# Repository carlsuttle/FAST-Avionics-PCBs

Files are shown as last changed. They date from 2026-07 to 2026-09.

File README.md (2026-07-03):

# FAST Avionics PCBs

KiCad 10 hardware designs for FAST avionics.

## Projects

- `FLIGHT CONTROLLER/` — FAST flight-controller schematic, PCB, fabrication outputs, component libraries, and design notes.
- `AS_GPS_XIAO_OUTBOARD/` — GPS/XIAO outboard schematic, PCB, fabrication outputs, and supporting libraries.

Open each `.kicad_pro` file with KiCad 10 or newer.

Local KiCad preferences, lock files, autosaves, backups, and history snapshots are intentionally excluded from version control.

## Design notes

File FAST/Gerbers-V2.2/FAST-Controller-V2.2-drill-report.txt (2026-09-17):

Drill report for FAST Controller.kicad_pcb
Created on 2026-09-17T15:46:22

Copper Layer Stackup:
    =============================================================
    L1 :  F.Cu                      front
    L2 :  B.Cu                      back

Drill file 'FAST Controller-PTH.drl' contains
    plated through holes:
    =============================================================
    T1  0.300mm  0.0118"  (19 holes))
    T2  0.400mm  0.0157"  (6 holes))
    T3  0.600mm  0.0236"  (2 holes))
    T4  0.700mm  0.0276"  (4 holes))
    T5  0.800mm  0.0315"  (36 holes))
    T6  0.889mm  0.0350"  (14 holes))
    T7  0.950mm  0.0374"  (36 holes))
    T8  1.000mm  0.0394"  (52 holes))

    Total plated holes count 169

Drill file 'FAST Controller-NPTH.drl' contains
    unplated through holes:
    =============================================================
    T1  3.200mm  0.1260"  (4 holes))

    Total unplated holes count 4

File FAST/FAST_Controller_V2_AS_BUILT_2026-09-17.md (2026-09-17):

# FAST Controller V2 as-built record — 2026-09-17

The manufactured FAST Controller V2 board has been installed and bench-tested
in the aircraft. The corrected production files are V2.2; they supersede the
V2.1 Gerbers.

## As-built corrections

- PMEG4050EP isolation diodes are installed in the corrected direction so the
  ESC BEC or power-module BEC can power `5V_LOGIC`, without `5V_LOGIC`
  back-feeding either BEC input.
- A field link connects the watchdog output/test point to CD74HCT157E select.
- A 10 kOhm pull-down from mux select to ground is fitted so loss of watchdog
  drive selects receiver PWM.
- The CRSF 5 V pin is intentionally unconnected. The receiver and servo rail
  are powered through the PWM harness: pin 5 ground and pin 6 ESC-BEC 5 V on
  each six-pin JST-XH receiver connector.
- The CRSF ground pad on its connector is not relied upon for receiver return;
  receiver ground is present through the PWM harness. A wire link to nearby
  ground test point TP3 remains the available repair if a dedicated CRSF
  ground is required.

## Confirmed connector/pin mapping

- J8 through J15 use the standard servo order: pin 1 ground, pin 2
  `+5V_ESC_BEC`, and pin 3 signal.
- J8 is servo output channel 1 and J15 is servo output channel 8.
- Board channel 8 (`TEENSY_PWM8_RAW`) is routed to Teensy D1, not Teensy D8.
- Teensy D8 is board channel 7 (`TEENSY_PWM7_RAW`).
- Flaps are therefore implemented in firmware as CRSF channel 8 -> Teensy D1
  -> board channel 8 -> J15.

## Integration result

All installed servo channels were confirmed operational from Teensy control,
and receiver PWM failover was confirmed through the hardware multiplexers.
IMU, ESP_AIR, ESP_OUTBOARD, CRSF, SD recording, file listing, and flight-log
replay were also verified after installation.

## V2.2 production correction

The PCB net assignments for J8 through J15 were corrected from the V2.1
pin-1-power/pin-2-ground order to pin 1 ground, pin 2 `+5V_ESC_BEC`, and pin 3
signal. Use `FAST-Controller-V2.2-Gerbers-2026-09-17.zip` for any new boards.

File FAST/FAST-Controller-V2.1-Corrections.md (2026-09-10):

# FAST Controller V2.1 — Production Corrections

Date: 2026-09-10

This note records faults discovered after manufacture of the original V2 board and the corrections incorporated into the V2.1 design files and manufacturing package.

## 1. CRSF receiver ground at J4

### Error

J4 pin 2 was assigned to GND in the schematic, but its copper-pour connection formed an isolated island. KiCad therefore showed the pad surrounded by GND-coloured copper even though it had no conductive path to the main board ground. The original DRC report's zone-to-zone unconnected warnings were incorrectly treated as harmless.

### V2.1 correction

The assembly requires an insulated wire link from **J4 pin 2 to TP3**. Both points are through-hole and TP3 is a confirmed main-ground point. The instruction is also printed on the bottom silkscreen:

`FIT INSULATED LINK: J4-2 TO TP3`

On already-manufactured V2 boards, fit the same link. J7/J8 grounds may provide another receiver-ground path in normal installation, but they are not a substitute for making the CRSF connector ground independently correct.

### Verification

Continuity test before power-up: J4 pin 2 to TP3 and to the Teensy GND pins must measure approximately zero ohms.

## 2. Logic-supply isolation diodes D1 and D2

### Error

D1 and D2 were electrically reversed. Their old orientation allowed the +5V_LOGIC rail to feed back toward the BEC source rails, opposite to the intended isolation behaviour.

### V2.1 correction

Both diode symbols and both PCB footprints have been reversed while retaining PMEG4050EP Schottky diodes:

- D1: anode to +5V_PM_BEC; cathode to +5V_LOGIC.
- D2: anode to +5V_ESC_BEC; cathode to +5V_LOGIC.

Either BEC can now supply +5V_LOGIC, while +5V_LOGIC cannot back-power either BEC rail. Observe the V2.1 footprint polarity marking when fitting the parts.

### Verification

With the board unpowered, diode-test mode should conduct from each BEC source rail toward +5V_LOGIC and block in the reverse direction.

## 3. Watchdog multiplexer-select default state

### Error

The ADM706 watchdog output drives MUX_SELECT, but the line had no discrete pull-down. Its fail-safe state could therefore be uncertain while the watchdog output or its supply was inactive.

### V2.1 correction

R30, 10 kΩ, 0805 hand-solder footprint, has been added from MUX_SELECT to GND. The resistor is connected directly to the existing MUX_SELECT trace and forces the receiver-PWM path to its safe default state when the watchdog is not actively driving the line.

### Verification

With the board unpowered, measure approximately 10 kΩ from MUX_SELECT to GND. During a watchdog timeout, confirm that MUX_SELECT is low and the CD74HCT157 multiplexers select the receiver PWM inputs.

## Manufacturing-package status

The corrected manufacturing output is identified as **FAST Controller V2.1**. Do not send the earlier V2 Gerber ZIP for a new production run. The V2.1 package includes the updated diode orientation, R30 pads and markings, board version marking, and the mandatory J4-to-TP3 insulated-link assembly instruction.

KiCad's final geometry check reports zero clearance, short-circuit, footprint, and silkscreen violations. It intentionally retains two unconnected-zone findings for the J4 ground island because the connection is completed by the specified insulated assembly link rather than PCB copper.

## Required pre-flight checks

1. Confirm the J4 pin 2 to TP3 link is installed and insulated.
2. Confirm D1 and D2 polarity by diode test.
3. Confirm +5V_ESC_BEC and +5V_PM_BEC are isolated from one another.
4. Confirm R30 measures 10 kΩ from MUX_SELECT to GND.
5. Power the board from each BEC source separately and verify +5V_LOGIC.
6. Test watchdog timeout and all eight receiver/Teensy servo-output paths before flight.

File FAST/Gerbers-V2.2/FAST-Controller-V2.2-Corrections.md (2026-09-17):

# FAST Controller V2.2 production correction

Date: 2026-09-17

V2.2 supersedes the V2.1 Gerbers. Servo output connectors J8 through J15 now
use the confirmed standard order:

- pin 1: GND
- pin 2: +5V_ESC_BEC
- pin 3: PWM signal

The +5V_ESC_BEC copper spine was rerouted from pin 1 to pin 2, and both copper
zones were refilled. KiCad DRC reports zero violations. Its two remaining
unconnected-item messages are the pre-existing duplicate ground-zone artifacts
at the zone origin (20.5 mm, 20.5 mm), not physical pads or routed nets.

Production archive: `FAST-Controller-V2.2-Gerbers-2026-09-17.zip`.

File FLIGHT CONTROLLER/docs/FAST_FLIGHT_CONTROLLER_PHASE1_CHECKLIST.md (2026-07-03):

# FAST Flight Controller Rev A, Phase 1 Checklist

- [x] Teensy library found
- [x] XIAO library found
- [x] Teensy symbol placed
- [x] XIAO symbol placed
- [x] Teensy footprint assigned
- [x] XIAO footprint assigned
- [x] FAST_SPI_SCK wired
- [x] FAST_SPI_MOSI_ESP_TO_TEENSY_SDI wired
- [x] FAST_SPI_MISO_TEENSY_SDO_TO_ESP wired
- [x] FAST_SPI_CS wired
- [x] FAST_DATA_READY wired
- [x] MOSI/MISO direction warning checked
- [x] No SD card wiring added in Phase 1
- [x] No PCB routing added in Phase 1
- [x] Schematic opens in KiCad
- [x] ERC status noted

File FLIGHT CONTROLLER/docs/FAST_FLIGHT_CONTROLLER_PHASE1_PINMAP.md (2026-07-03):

# FAST Flight Controller Rev A, Phase 1 Pinmap

## Core Teensy <-> ESP_AIR Transport Mapping

```text
Teensy pin 13 -> ESP GPIO7  / D8   SCK
Teensy pin 12 -> ESP GPIO8  / D9   ESP MOSI -> Teensy slave SDI
Teensy pin 11 -> ESP GPIO9  / D10  ESP MISO <- Teensy slave SDO
Teensy pin 10 -> ESP GPIO44 / D7   CS
Teensy pin 9  -> ESP GPIO43 / D6   DATA_READY
```

## MOSI/MISO Direction Warning

ESP32-S3 is the SPI master.
Teensy 4.0 is the SPI slave.
Do not map MOSI/MISO by matching Teensy silkscreen labels.
Map by signal direction:
ESP MOSI drives Teensy slave SDI.
ESP MISO receives Teensy slave SDO.

## Phase 1 Net Labels

```text
FAST_SPI_SCK
FAST_SPI_MOSI_ESP_TO_TEENSY_SDI
FAST_SPI_MISO_TEENSY_SDO_TO_ESP
FAST_SPI_CS
FAST_DATA_READY
```

## Phase 1 Scope Notes

SD card pins are not wired in Phase 1.
Power input, regulation, and protection circuits are not designed in Phase 1.
PCB placement and routing are not part of Phase 1.

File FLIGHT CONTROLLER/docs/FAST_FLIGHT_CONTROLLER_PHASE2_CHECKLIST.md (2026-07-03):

# FAST Flight Controller Rev A - Phase 2 Checklist

- [x] ESC/BEC input connector added
- [x] `+5V_ESC_BEC` net created
- [x] Teensy VIN connected to `+5V_ESC_BEC`
- [x] XIAO VBUS/5V connected to `+5V_ESC_BEC`
- [x] All current module GND pins connected
- [x] Input capacitors added
- [x] Test points added
- [x] `TEENSY_3V3` and `ESP_3V3` not shorted together
- [x] Phase 1 transport nets preserved
- [x] SD pins reserved, not no-connected
- [x] No SD card wiring added in Phase 2
- [x] No PCB routing added in Phase 2
- [x] ERC run
- [x] ERC report saved

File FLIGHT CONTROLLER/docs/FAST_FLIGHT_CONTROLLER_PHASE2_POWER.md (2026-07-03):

# FAST Flight Controller Rev A - Phase 2 Power

## Power Source

The board is powered from an external ESC/BEC that provides regulated `+5V_ESC_BEC` and `GND`.

No onboard regulator was added in Phase 2.
No PCB placement or routing was added in Phase 2.

## 5 V Distribution

`+5V_ESC_BEC` powers:

- J1 pin 1, `ESC_BEC_5V_IN`
- U1 Teensy 4.0 carrier `VIN`
- U2 XIAO ESP32-S3 `VBUS` / 5 V input
- C1, C2, C3 input capacitors
- TP1 test point

J1 pin 2 is connected to `GND`.

## Ground

`GND` connects:

- J1 pin 2
- U1 Teensy `GND1` and `GND2`
- U2 XIAO `GND`
- C1, C2, C3 return pins
- TP2 test point

## 3.3 V Rails

The Teensy and XIAO 3.3 V pins are treated as module-generated rails.

- U1 Teensy `3V3` is labeled `TEENSY_3V3` and connects only to TP3.
- U2 XIAO `3V3` is labeled `ESP_3V3` and connects only to TP4.

`TEENSY_3V3` and `ESP_3V3` are not connected together in Phase 2.
Neither 3.3 V rail is used as the main board power input.

## Input Capacitors

- C1: `100 uF >=10V bulk`, provisional footprint `fast_teensy:C_Radial_D5.0mm_P2.00mm`
- C2: `10 uF >=10V`, provisional footprint `fast_teensy:C_0805`
- C3: `100 nF`, provisional footprint `fast_teensy:C_0805`

All three capacitors connect from `+5V_ESC_BEC` to `GND`.

## Test Points

- TP1: `+5V_ESC_BEC`
- TP2: `GND`
- TP3: `TEENSY_3V3`
- TP4: `ESP_3V3`

## Reserved Pins

No SD card wiring was added in Phase 2.
ESP GPIO1 / D0, GPIO2 / D1, GPIO5 / D4, and GPIO6 / D5 remain reserved for Phase 3 SD card wiring and were not no-connected.

## Remaining ERC Status

ERC was run and saved to `docs/FAST_FLIGHT_CONTROLLER_PHASE2_ERC.rpt`.

Remaining electrical errors are unconnected pins left open for later phases or future design decisions. They were not hidden with no-connect markers.

The ERC report also contains footprint-link warnings for the local `fast_teensy` footprint nickname even though the project-local `fp-lib-table` contains the `fast_teensy` entry and the footprints exist under `${KIPRJMOD}/lib/footprints/fast_teensy.pretty`. These warnings are documented and not suppressed.

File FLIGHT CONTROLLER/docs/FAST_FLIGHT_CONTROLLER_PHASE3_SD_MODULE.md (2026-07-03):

# FAST Flight Controller Phase 3 SD Module

## Design

J2 is a plug-in SD-card breakout module, not a raw microSD socket. The module is intended to be soldered into the FAST Flight Controller PCB so that its daughterboard stands vertically, perpendicular to the main PCB.

J2 uses the project-local symbol `fast_common:SD_Module_1x06` and the provisional footprint `fast_common:SD_Module_1x06_Vertical_Daughterboard`.

## Header Pin Order

The module label order, from top to bottom, is:

| Pin | Label |
| --- | --- |
| 1 | CS |
| 2 | SCK |
| 3 | MOSI |
| 4 | MISO |
| 5 | VCC |
| 6 | GND |

## Electrical Connections

| J2 pin | Net | ESP_AIR connection |
| --- | --- | --- |
| 1 CS | `ESP_SD_CS` | U2 GPIO2 / D1 |
| 2 SCK | `ESP_SD_SCK` | U2 GPIO5 / D4 |
| 3 MOSI | `ESP_SD_MOSI` | U2 GPIO6 / D5 |
| 4 MISO | `ESP_SD_MISO` | U2 GPIO1 / D0 |
| 5 VCC | `+5V_ESC_BEC` | External regulated 5 V BEC rail |
| 6 GND | `GND` | Common ground |

VCC currently connects to `+5V_ESC_BEC` because the selected style of SD breakout module appears to include onboard 3.3 V regulation and interface circuitry. Do not change J2 VCC to `ESP_3V3` unless the exact physical module is later confirmed to require a 3.3 V input.

## Mechanical Notes

The physical module, header side, pin-1 position, board-facing side, and clearance envelope must be visually checked against the provisional footprint before PCB layout.

Mechanical support or retention may be needed because the SD module stands vertically and can apply leverage to the six-pin soldered header during card insertion, removal, vibration, or impact.

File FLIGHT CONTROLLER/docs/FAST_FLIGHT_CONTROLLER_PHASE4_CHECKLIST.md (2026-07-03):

# FAST Flight Controller Phase 4 Checklist

- [x] J3 IMU connector added
- [x] J4 CRSF connector added
- [x] J5 AS_GPS_XIAO_OUTBOARD connector added
- [x] J3 power pin correct: pin 1 = `+5V_ESC_BEC`
- [x] J3 is not connected to `TEENSY_3V3`
- [x] J3 ground pin correct: pin 2 = `GND`
- [x] J4 power pin correct: pin 1 = `+5V_ESC_BEC`
- [x] J4 ground pin correct: pin 2 = `GND`
- [x] J5 power pin correct: pin 1 = `+5V_ESC_BEC`
- [x] J5 ground pin correct: pin 2 = `GND`
- [x] J5 UART connected to old GPS UART pins: D0/RX1 and D1/TX1
- [x] Old offboard magnetometer I2C not routed to J5
- [x] J5 pins 5/6 preserved as spares and not routed to ESP32 GPIOs
- [x] No existing Teensy to ESP32 transport nets changed
- [x] No SD module nets changed
- [x] `+5V_ESC_BEC` preserved
- [x] `TEENSY_3V3` and `ESP_3V3` remain separate
- [x] Netlist export passed
- [x] ERC run
- [x] Remaining ERC errors explained in `FAST_FLIGHT_CONTROLLER_PHASE4_ERC.rpt`
- [x] No PCB placement or routing performed

## Pending

- [ ] Final J5 connector footprint selection, preferably JST-XH 1x06 2.50 mm if that is the selected physical connector
- [ ] Confirm whether `IMU_INT` should connect to a Teensy GPIO
- [ ] Confirm whether `IMU_CS_OR_AUX` should connect to a Teensy GPIO

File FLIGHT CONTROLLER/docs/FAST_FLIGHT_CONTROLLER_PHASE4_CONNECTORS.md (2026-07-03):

# FAST Flight Controller Phase 4 Connectors

## Scope

Phase 4 adds schematic-only external connectors for IMU, CRSF receiver/radio, and `AS_GPS_XIAO_OUTBOARD`.

No PCB placement, routing, or board-outline work was performed.

## Confirmed Source References

Confirmed Teensy assignments came from:

- `C:\Users\dell\Platformio\esp32_crsf_telemetry\Teensy_ESP_AIR_GND_88cb9aa\Teensy\src\config.h`
  - lines 17-20: CRSF uses Teensy `Serial2`, `TX=8`, `RX=7`.
  - lines 24-27: GPS uses Teensy `Serial1`, `TX=1`, `RX=0`.
  - lines 30-32: I2C uses `SDA=18`, `SCL=19`.
- `C:\Users\dell\Platformio\esp32_crsf_telemetry\Teensy_ESP_AIR_GND_88cb9aa\Teensy\README.md`
  - lines 64-72 confirm CRSF and GPS serial assignments.
  - lines 75-76 confirm Teensy I2C pins.

Phase 5 updated the CRSF Teensy pins to match the newer local codebase:

- `C:\Users\dell\Platformio\Avionics Lab\include\config.h`
  - lines 22-23: `PIN_CRSF_RX = 15`, `PIN_CRSF_TX = 14`.

## J3 IMU

Symbol: `fast_common:PinHeader_1x06`

Footprint: `fast_common:PinHeader_1x06_P2.54mm`

| Pin | Net | Status |
| --- | --- | --- |
| 1 | `+5V_ESC_BEC` | connected |
| 2 | `GND` | connected |
| 3 | `IMU_SCL` | connected to U1 D19 / SCL |
| 4 | `IMU_SDA` | connected to U1 D18 / SDA |
| 5 | `IMU_INT` | provisional connector net only |
| 6 | `IMU_CS_OR_AUX` | provisional connector net only |

The IMU connector is powered from `+5V_ESC_BEC`, not `TEENSY_3V3`. The IMU breakout must provide Teensy-safe 3.3 V logic on `IMU_SCL` and `IMU_SDA`, or external level shifting is required.

`IMU_SCL` and `IMU_SDA` are connected because the Teensy I2C bus assignment is confirmed. No confirmed Teensy pins were found for `IMU_INT` or `IMU_CS_OR_AUX`, so those remain pending.

## J4 CRSF_RX

Symbol: `fast_common:PinHeader_1x04`

Footprint: `fast_common:PinHeader_1x04_P2.54mm`

| Pin | Net | Status |
| --- | --- | --- |
| 1 | `+5V_ESC_BEC` | connected |
| 2 | `GND` | connected |
| 3 | `CRSF_RX_TO_TEENSY` | connected to U1 D15 / RX3 |
| 4 | `CRSF_TX_FROM_TEENSY` | connected to U1 D14 / TX3 |

CRSF uses the newer `Serial3` assignment from the current local codebase: Teensy RX15 receives receiver TX, and Teensy TX14 drives receiver RX. The CRSF net names were preserved.

## J5 AS_GPS_XIAO_OUTBOARD

Symbol: `fast_common:PinHeader_1x06`

Footprint: `fast_common:PinHeader_1x06_P2.54mm`

The exact JST-XH 1x06 footprint remains pending; the current footprint is a provisional 2.54 mm through-hole header.

| Pin | Net | Status |
| --- | --- | --- |
| 1 | `+5V_ESC_BEC` | connected |
| 2 | `GND` | connected |
| 3 | `OUTBOARD_TX_TO_TEENSY_RX` | connected to U1 D0 / RX1 |
| 4 | `OUTBOARD_RX_FROM_TEENSY_TX` | connected to U1 D1 / TX1 |
| 5 | `OUTBOARD_SPARE1` | physically present, not routed to Teensy or ESP32 GPIO |
| 6 | `OUTBOARD_SPARE2` | physically present, not routed to Teensy or ESP32 GPIO |

`AS_GPS_XIAO_OUTBOARD` uses the previous GPS UART pins. The old GPS Teensy RX pin is D0, and the old GPS Teensy TX pin is D1.

Former offboard magnetometer I2C pins are now unused for J5. `IMU_SCL` and `IMU_SDA` are not routed to `AS_GPS_XIAO_OUTBOARD`.

## Preserved Nets

Phase 1 Teensy-to-ESP32 transport nets were preserved:

- `FAST_SPI_SCK`
- `FAST_SPI_MOSI_ESP_TO_TEENSY_SDI`
- `FAST_SPI_MISO_TEENSY_SDO_TO_ESP`
- `FAST_SPI_CS`
- `FAST_DATA_READY`

Phase 2 power nets were preserved:

- `+5V_ESC_BEC`
- `GND`
- `TEENSY_3V3`
- `ESP_3V3`

`TEENSY_3V3` and `ESP_3V3` remain separate.

Phase 3 SD module wiring was preserved:

- `ESP_SD_CS`
- `ESP_SD_SCK`
- `ESP_SD_MOSI`
- `ESP_SD_MISO`
- J2 VCC on `+5V_ESC_BEC`
- J2 GND on `GND`

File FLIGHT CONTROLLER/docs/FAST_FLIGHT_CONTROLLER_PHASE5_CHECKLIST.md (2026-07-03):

# FAST Flight Controller Phase 5 Checklist

- [x] J3 IMU pin 1 confirmed as `+5V_ESC_BEC`
- [x] Servo connector footprint available: `fast_common:PinHeader_1x03_P2.54mm`
- [x] CH1 A/B connectors added
- [x] CH2 A/B connectors added
- [x] CH3 A/B connectors added
- [x] CH4 A/B connectors added
- [x] CH5 A/B connectors added
- [x] CH6 spare PWM connector added because it is defined in the source pin map
- [x] A/B connectors share the same PWM net per channel
- [x] All servo pin 1 pins connected to `+5V_ESC_BEC`
- [x] All servo pin 2 pins connected to `GND`
- [x] All servo pin 3 pins connected to correct PWM signal nets
- [x] Teensy PWM pin map source documented
- [x] No servo power connected to `TEENSY_3V3`
- [x] No servo power connected to `ESP_3V3`
- [x] CRSF nets preserved by name and updated to current-code U1 D15/D14 pins
- [x] Phase 1 transport nets preserved
- [x] SD module nets preserved
- [x] IMU nets preserved
- [x] AS_GPS_XIAO_OUTBOARD nets preserved
- [x] Netlist export passed
- [x] ERC run
- [x] Remaining ERC items explained in `FAST_FLIGHT_CONTROLLER_PHASE5_ERC.rpt`
- [x] No PCB placement or routing performed

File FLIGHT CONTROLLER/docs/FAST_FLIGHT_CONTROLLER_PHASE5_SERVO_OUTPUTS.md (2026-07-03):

# FAST Flight Controller Phase 5 Servo Outputs

## Scope

Phase 5 adds schematic-only RC servo output connectors. No PCB placement, routing, trace sizing, or board-outline work was performed.

Servo connector standard for every output:

| Pin | Net |
| --- | --- |
| 1 | `+5V_ESC_BEC` |
| 2 | `GND` |
| 3 | PWM signal |

The first five channels have two physical connectors each. The A/B connectors for a channel share the same PWM signal net.

Servo power is `+5V_ESC_BEC`. Servo current must be considered during PCB layout, including trace width, connector current rating, and BEC current capacity.

## Source Pin Map

The Teensy PWM pin assignment comes from:

- `C:\Users\dell\Platformio\Avionics Lab\include\teensy_pinmap.h`
  - line 7: `kTeensyPwmAileronPin = 2`
  - line 8: `kTeensyPwmElevatorPin = 3`
  - line 9: `kTeensyPwmThrottlePin = 4`
  - line 10: `kTeensyPwmRudderPin = 5`
  - line 11: `kTeensyPwmFlapsPin = 7`
  - line 12: `kTeensyPwmSparePin = 8`

The newer CRSF pin assignment comes from:

- `C:\Users\dell\Platformio\Avionics Lab\include\config.h`
  - line 22: `PIN_CRSF_RX = 15`
  - line 23: `PIN_CRSF_TX = 14`

CRSF net names are preserved, but the Teensy pins are updated to D15/D14 so D7/D8 can be used for PWM outputs.

## Servo Connectors

| Channel | Function | Connector | Signal net | Teensy pin |
| --- | --- | --- | --- | --- |
| CH1 | Aileron | `J6A` / `J6B` | `SERVO_CH1_PWM` | U1 D2 |
| CH2 | Elevator | `J7A` / `J7B` | `SERVO_CH2_PWM` | U1 D3 |
| CH3 | Throttle | `J8A` / `J8B` | `SERVO_CH3_PWM` | U1 D4 |
| CH4 | Rudder | `J9A` / `J9B` | `SERVO_CH4_PWM` | U1 D5 |
| CH5 | Flaps | `J10A` / `J10B` | `SERVO_CH5_PWM` | U1 D7 |
| CH6 | Spare PWM | `J11` | `SERVO_CH6_PWM` | U1 D8 |

Symbol used for every servo connector: `fast_common:PinHeader_1x03`

Footprint used for every servo connector: `fast_common:PinHeader_1x03_P2.54mm`

Do not use `TEENSY_3V3` or `ESP_3V3` for servo power.

Netlist export passed. KiCad reports an annotation warning because the requested connector references use the `J6A`/`J6B` style rather than ending in a digit.

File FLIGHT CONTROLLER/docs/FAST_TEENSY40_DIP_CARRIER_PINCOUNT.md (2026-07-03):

# FAST Teensy 4.0 DIP Carrier Pin-Count Report

Symbol: `fast_teensy:FAST_Teensy40_DIP_Carrier`
Footprint: `fast_teensy:FAST_Teensy40_DIP_Carrier`

This FAST-specific carrier part exposes only the normal Teensy 4.0 side-header/socket contacts used by a plug-in module. It intentionally does not expose underside pads, SD pads, USB host pads, or test pads.

Symbol pin count: 28
Footprint pad count: 28

## Symbol Pins
- `GND1`
- `D0`
- `D1`
- `D2`
- `D3`
- `D4`
- `D5`
- `D6`
- `D7`
- `D8`
- `D9`
- `D10`
- `D11`
- `D12`
- `VIN`
- `GND2`
- `3V3`
- `D23`
- `D22`
- `D21`
- `D20`
- `D19`
- `D18`
- `D17`
- `D16`
- `D15`
- `D14`
- `D13`

## Footprint Pads
- `GND1`
- `D0`
- `D1`
- `D2`
- `D3`
- `D4`
- `D5`
- `D6`
- `D7`
- `D8`
- `D9`
- `D10`
- `D11`
- `D12`
- `VIN`
- `GND2`
- `3V3`
- `D23`
- `D22`
- `D21`
- `D20`
- `D19`
- `D18`
- `D17`
- `D16`
- `D15`
- `D14`
- `D13`

## Symbol-to-Footprint Mapping
| Symbol pin | Footprint pad |
|---|---|
| `GND1` | `GND1` |
| `D0` | `D0` |
| `D1` | `D1` |
| `D2` | `D2` |
| `D3` | `D3` |
| `D4` | `D4` |
| `D5` | `D5` |
| `D6` | `D6` |
| `D7` | `D7` |
| `D8` | `D8` |
| `D9` | `D9` |
| `D10` | `D10` |
| `D11` | `D11` |
| `D12` | `D12` |
| `VIN` | `VIN` |
| `GND2` | `GND2` |
| `3V3` | `3V3` |
| `D23` | `D23` |
| `D22` | `D22` |
| `D21` | `D21` |
| `D20` | `D20` |
| `D19` | `D19` |
| `D18` | `D18` |
| `D17` | `D17` |
| `D16` | `D16` |
| `D15` | `D15` |
| `D14` | `D14` |
| `D13` | `D13` |

## Phase 1 Required Pins
| Signal | Teensy carrier pin | ESP_AIR pin |
|---|---|---|
| `FAST_SPI_SCK` | `D13` | GPIO7 / D8 |
| `FAST_SPI_MOSI_ESP_TO_TEENSY_SDI` | `D12` | GPIO8 / D9 |
| `FAST_SPI_MISO_TEENSY_SDO_TO_ESP` | `D11` | GPIO9 / D10 |
| `FAST_SPI_CS` | `D10` | GPIO44 / D7 |
| `FAST_DATA_READY` | `D9` | GPIO43 / D6 |

54-pin Teensy symbol/footprint remains in use: NO. The schematic no longer references `teensy:Teensy4.0` or `teensy:Teensy40`.

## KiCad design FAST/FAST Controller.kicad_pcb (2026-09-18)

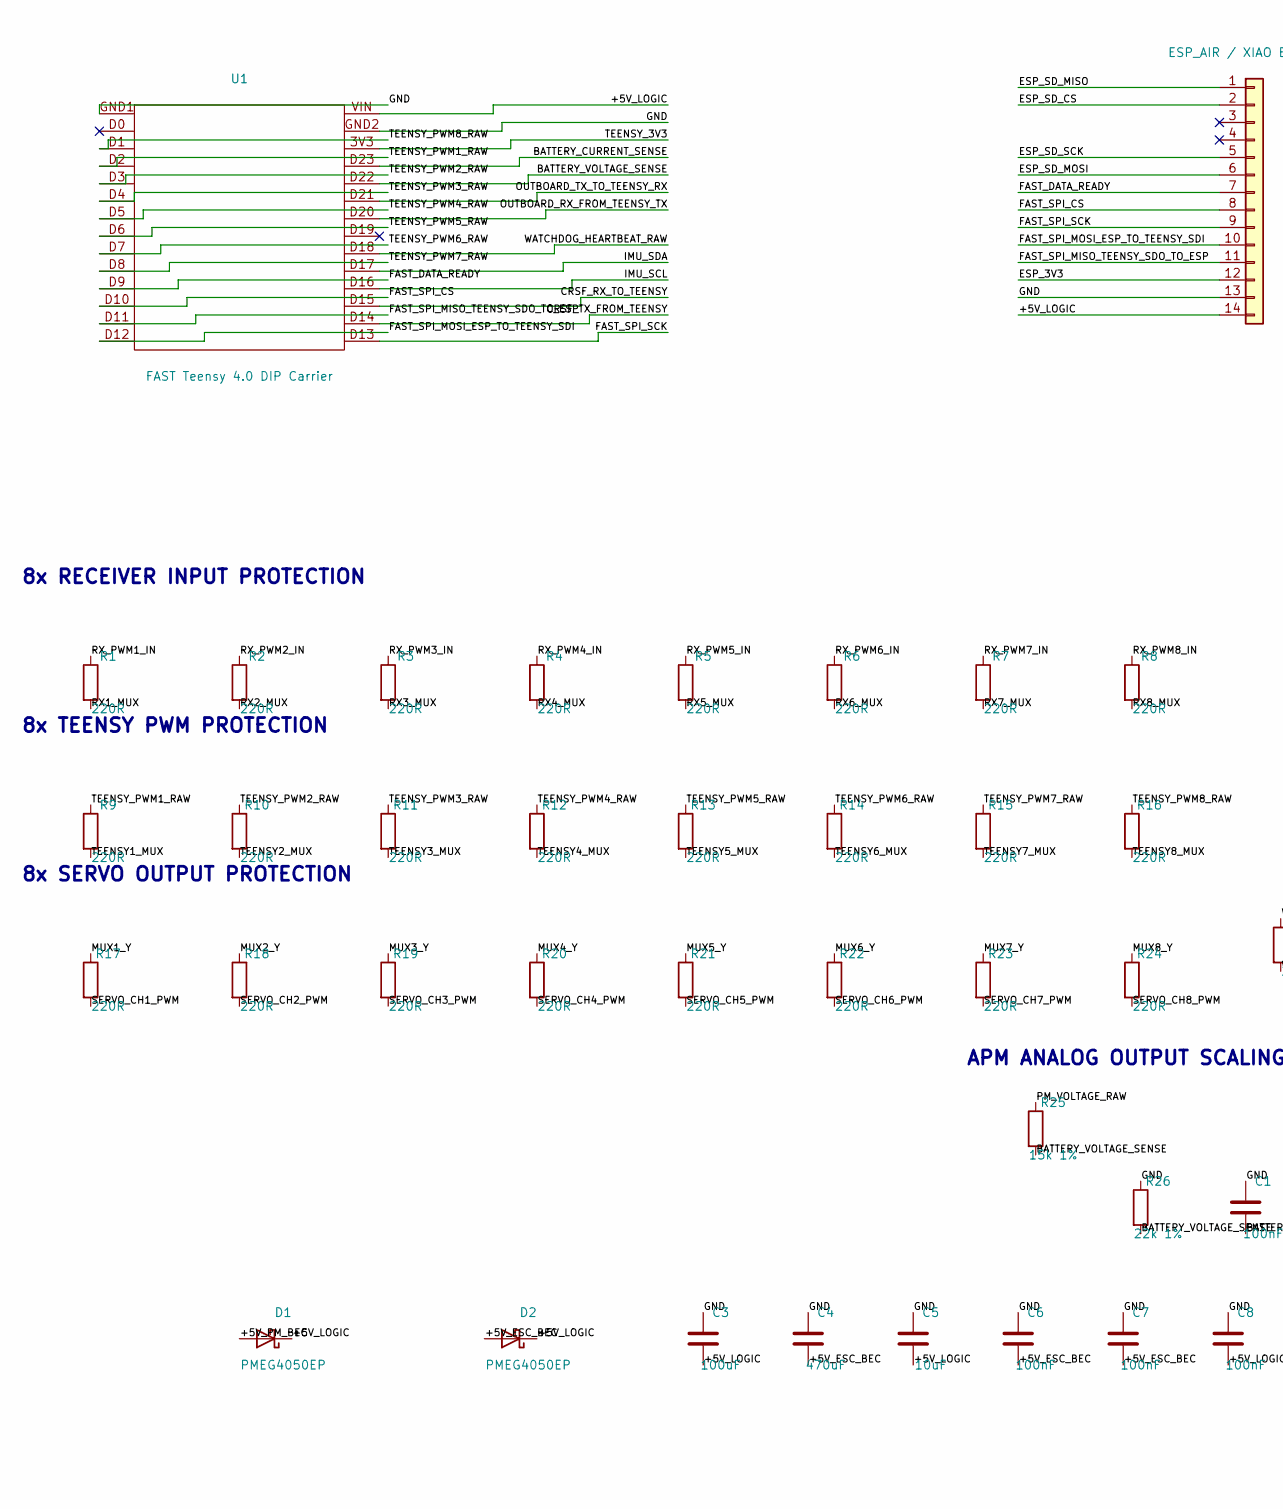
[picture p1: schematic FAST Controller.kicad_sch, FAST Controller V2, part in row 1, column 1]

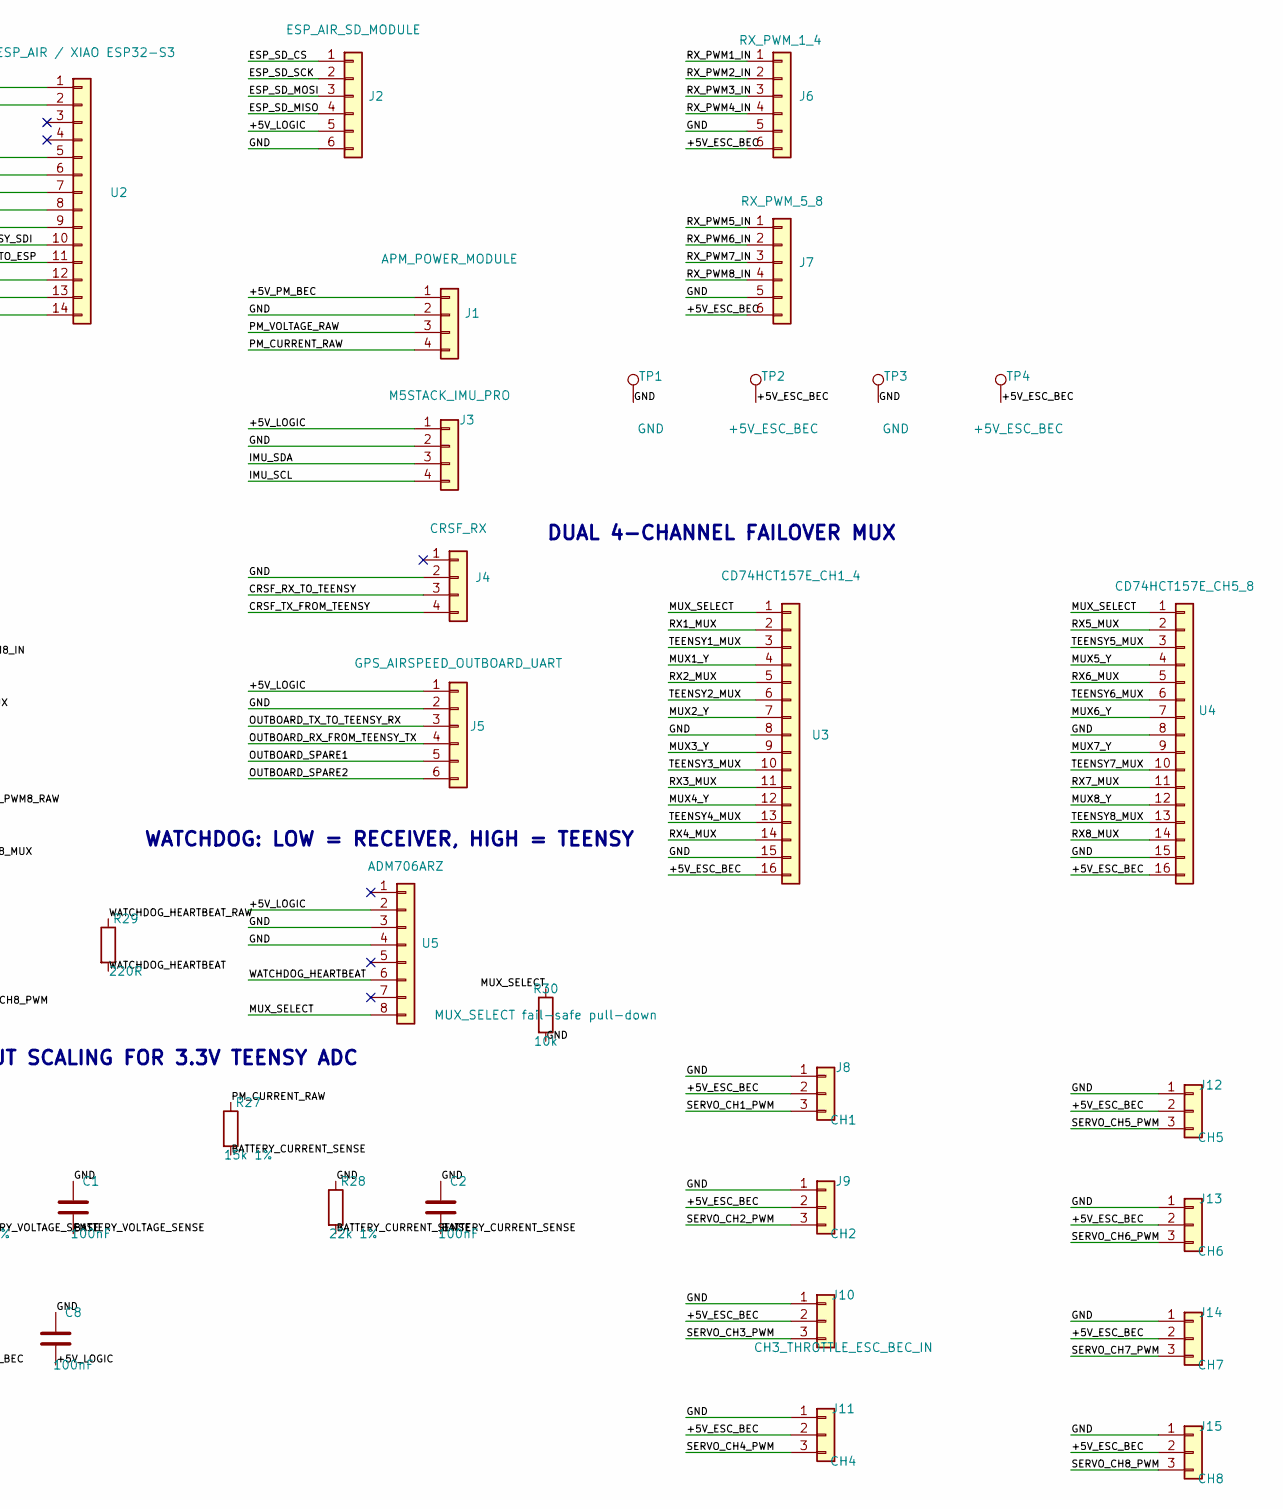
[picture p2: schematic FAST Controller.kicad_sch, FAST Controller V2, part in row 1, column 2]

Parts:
C1, C2, C6, C7, C8: 100nF; C_0805_2012Metric_Pad1.18x1.45mm_HandSolder
C3: 100uF; CP_Radial_D5.0mm_P2.00mm
C4: 470uF; CP_Radial_D8.0mm_P3.50mm
C5: 10uF; C_0805_2012Metric_Pad1.18x1.45mm_HandSolder
D1, D2: PMEG4050EP; D_SOD-128
J1: APM_POWER_MODULE; JST_XH_B4B-XH-A_1x04_P2.50mm_Vertical
J2: ESP_AIR_SD_MODULE; JST_XH_B6B-XH-A_1x06_P2.50mm_Vertical
J3: M5STACK_IMU_PRO; JST_XH_B4B-XH-A_1x04_P2.50mm_Vertical
J4: CRSF_RX; JST_XH_B4B-XH-A_1x04_P2.50mm_Vertical
J5: GPS_AIRSPEED_OUTBOARD_UART; JST_XH_B6B-XH-A_1x06_P2.50mm_Vertical
J6: RX_PWM_1_4; JST_XH_B6B-XH-A_1x06_P2.50mm_Vertical
J7: RX_PWM_5_8; JST_XH_B6B-XH-A_1x06_P2.50mm_Vertical
J8: CH1; PinHeader_1x03_P2.54mm_Vertical
J9: CH2; PinHeader_1x03_P2.54mm_Vertical
J10: CH3_THROTTLE_ESC_BEC_IN; PinHeader_1x03_P2.54mm_Vertical
J11: CH4; PinHeader_1x03_P2.54mm_Vertical
J12: CH5; PinHeader_1x03_P2.54mm_Vertical
J13: CH6; PinHeader_1x03_P2.54mm_Vertical
J14: CH7; PinHeader_1x03_P2.54mm_Vertical
J15: CH8; PinHeader_1x03_P2.54mm_Vertical
R1, R2, R3, R4, R5, R6, R7, R8, R9, R10, R11, R12, R13, R14, R15, R16, R17, R18, R19, R20, R21, R22, R23, R24, R29: 220R; R_0805_2012Metric_Pad1.20x1.40mm_HandSolder
R25, R27: 15k 1%; R_0805_2012Metric_Pad1.20x1.40mm_HandSolder
R26, R28: 22k 1%; R_0805_2012Metric_Pad1.20x1.40mm_HandSolder
R30: 10k; R_0805_2012Metric_Pad1.20x1.40mm_HandSolder
TP1, TP3: GND; TestPoint_THTPad_D1.5mm_Drill0.7mm
TP2, TP4: +5V_ESC_BEC; TestPoint_THTPad_D1.5mm_Drill0.7mm
U1: FAST Teensy 4.0 DIP Carrier; FAST_Teensy40_DIP_Carrier
U2: ESP_AIR / XIAO ESP32-S3; XIAO-ESP32-S3-DIP
U3: CD74HCT157E_CH1_4; DIP-16_W7.62mm_LongPads
U4: CD74HCT157E_CH5_8; DIP-16_W7.62mm_LongPads
U5: ADM706ARZ; SOIC-8_3.9x4.9mm_P1.27mm

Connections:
/+5V_ESC_BEC: C4.1, C6.2, C7.2, D2.2 (A), J6.6, J7.6, J8.2, J9.2, J10.2, J11.2, J12.2, J13.2, J14.2, J15.2, TP2.1, TP4.1, U3.16, U4.16
/+5V_LOGIC: C3.1, C5.2, C8.2, D1.1 (K), D2.1 (K), J2.5, J3.1, J5.1, U1.VIN (VIN_/_5V), U2.14, U5.2
/+5V_PM_BEC: D1.2 (A), J1.1
/BATTERY_CURRENT_SENSE: C2.2, R27.2, R28.2, U1.D23 (D23_/_A9)
/BATTERY_VOLTAGE_SENSE: C1.2, R25.2, R26.2, U1.D22 (D22_/_A8)
/CRSF_RX_TO_TEENSY: J4.3, U1.D15 (D15_/_A1)
/CRSF_TX_FROM_TEENSY: J4.4, U1.D14 (D14_/_A0)
/ESP_3V3: U2.12
/ESP_SD_CS: J2.1, U2.2
/ESP_SD_MISO: J2.4, U2.1
/ESP_SD_MOSI: J2.3, U2.6
/ESP_SD_SCK: J2.2, U2.5
/FAST_DATA_READY: U1.D9 (D9_/_DATA_READY), U2.7
/FAST_SPI_CS: U1.D10 (D10_/_CS), U2.8
/FAST_SPI_MISO_TEENSY_SDO_TO_ESP: U1.D11 (D11_/_SPI_SDO), U2.11
/FAST_SPI_MOSI_ESP_TO_TEENSY_SDI: U1.D12 (D12_/_SPI_SDI), U2.10
/FAST_SPI_SCK: U1.D13 (D13_/_SCK_/_LED), U2.9
/GND: C1.1, C2.1, C3.2, C4.2, C5.1, C6.1, C7.1, C8.1, J1.2, J2.6, J3.2, J4.2, J5.2, J6.5, J7.5, J8.1, J9.1, J10.1, J11.1, J12.1, J13.1, J14.1, J15.1, R26.1, R28.1, R30.2, TP1.1, TP3.1, U1.GND1 (GND), U1.GND2 (GND), U2.13, U3.8, U3.15, U4.8, U4.15, U5.3, U5.4
/IMU_SCL: J3.4, U1.D16 (D16_/_A2)
/IMU_SDA: J3.3, U1.D17 (D17_/_A3)
/MUX1_Y: R17.1, U3.4
/MUX2_Y: R18.1, U3.7
/MUX3_Y: R19.1, U3.9
/MUX4_Y: R20.1, U3.12
/MUX5_Y: R21.1, U4.4
/MUX6_Y: R22.1, U4.7
/MUX7_Y: R23.1, U4.9
/MUX8_Y: R24.1, U4.12
/MUX_SELECT: R30.1, U3.1, U4.1, U5.8
/OUTBOARD_RX_FROM_TEENSY_TX: J5.4, U1.D20 (D20_/_A6)
/OUTBOARD_SPARE1: J5.5
/OUTBOARD_SPARE2: J5.6
/OUTBOARD_TX_TO_TEENSY_RX: J5.3, U1.D21 (D21_/_A7)
/PM_CURRENT_RAW: J1.4, R27.1
/PM_VOLTAGE_RAW: J1.3, R25.1
/RX1_MUX: R1.2, U3.2
/RX2_MUX: R2.2, U3.5
/RX3_MUX: R3.2, U3.11
/RX4_MUX: R4.2, U3.14
/RX5_MUX: R5.2, U4.2
/RX6_MUX: R6.2, U4.5
/RX7_MUX: R7.2, U4.11
/RX8_MUX: R8.2, U4.14
/RX_PWM1_IN: J6.1, R1.1
/RX_PWM2_IN: J6.2, R2.1
/RX_PWM3_IN: J6.3, R3.1
/RX_PWM4_IN: J6.4, R4.1
/RX_PWM5_IN: J7.1, R5.1
/RX_PWM6_IN: J7.2, R6.1
/RX_PWM7_IN: J7.3, R7.1
/RX_PWM8_IN: J7.4, R8.1
/SERVO_CH1_PWM: J8.3, R17.2
/SERVO_CH2_PWM: J9.3, R18.2
/SERVO_CH3_PWM: J10.3, R19.2
/SERVO_CH4_PWM: J11.3, R20.2
/SERVO_CH5_PWM: J12.3, R21.2
/SERVO_CH6_PWM: J13.3, R22.2
/SERVO_CH7_PWM: J14.3, R23.2
/SERVO_CH8_PWM: J15.3, R24.2
/TEENSY1_MUX: R9.2, U3.3
/TEENSY2_MUX: R10.2, U3.6
/TEENSY3_MUX: R11.2, U3.10
/TEENSY4_MUX: R12.2, U3.13
/TEENSY5_MUX: R13.2, U4.3
/TEENSY6_MUX: R14.2, U4.6
/TEENSY7_MUX: R15.2, U4.10
/TEENSY8_MUX: R16.2, U4.13
/TEENSY_3V3: U1.3V3
/TEENSY_PWM1_RAW: R9.1, U1.D2
/TEENSY_PWM2_RAW: R10.1, U1.D3
/TEENSY_PWM3_RAW: R11.1, U1.D4
/TEENSY_PWM4_RAW: R12.1, U1.D5
/TEENSY_PWM5_RAW: R13.1, U1.D6
/TEENSY_PWM6_RAW: R14.1, U1.D7
/TEENSY_PWM7_RAW: R15.1, U1.D8
/TEENSY_PWM8_RAW: R16.1, U1.D1 (D1_/_TX1)
/WATCHDOG_HEARTBEAT: R29.2, U5.6
/WATCHDOG_HEARTBEAT_RAW: R29.1, U1.D18 (D18_/_A4_/_SDA)

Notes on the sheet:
8x RECEIVER INPUT PROTECTION
APM ANALOG OUTPUT SCALING FOR 3.3V TEENSY ADC
8x TEENSY PWM PROTECTION
WATCHDOG: LOW = RECEIVER, HIGH = TEENSY
8x SERVO OUTPUT PROTECTION
DUAL 4-CHANNEL FAILOVER MUX

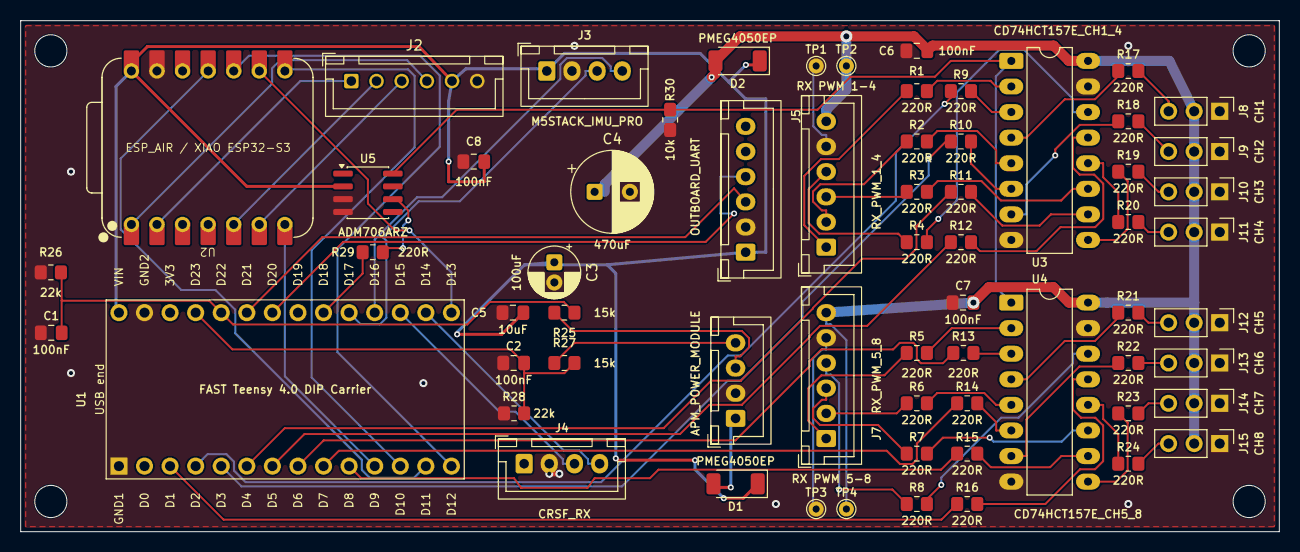
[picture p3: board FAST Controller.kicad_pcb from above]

Board: 2 copper layers, 125.0 x 50.8 mm, 68 parts (0 on the bottom side), 74 nets.

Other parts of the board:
H1, H2, H3, H4: MountingHole_3.2mm_M3

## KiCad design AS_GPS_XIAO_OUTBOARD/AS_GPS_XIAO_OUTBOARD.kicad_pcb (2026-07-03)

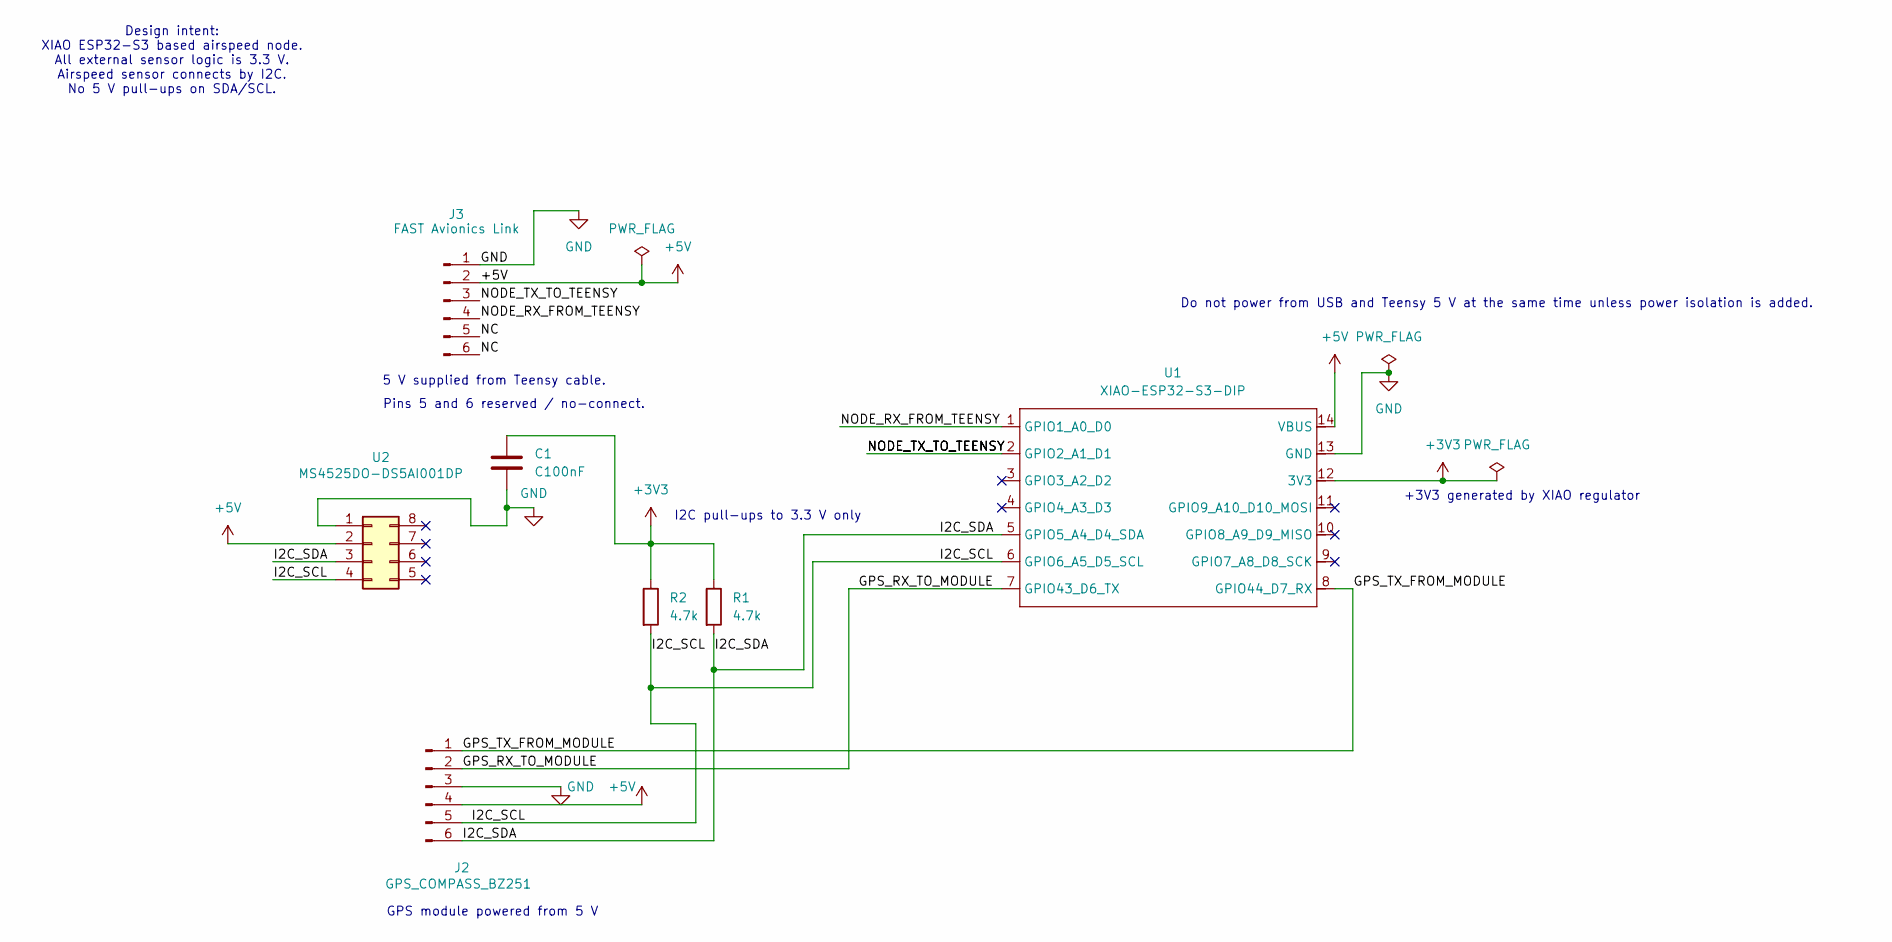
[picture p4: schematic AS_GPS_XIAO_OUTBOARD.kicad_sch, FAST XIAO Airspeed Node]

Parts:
C1: C100nF; C_0805_2012Metric
J2: GPS_COMPASS_BZ251; JST_XH_B6B-XH-A_1x06_P2.50mm_Vertical
J3: FAST Avionics Link; JST_XH_B6B-XH-A_1x06_P2.50mm_Vertical
R1, R2: 4.7k; R_0805_2012Metric
U1: XIAO-ESP32-S3-DIP
U2: MS4525DO-DS5AI001DP; DIP-8_W7.62mm

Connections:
+3V3: C1.1, R1.1, R2.1, U1.12 (3V3)
+5V: J2.4, J3.2, U1.14 (VBUS), U2.2
/GPS_RX_TO_MODULE: J2.2, U1.7 (GPIO43_D6_TX)
/GPS_TX_FROM_MODULE: J2.1, U1.8 (GPIO44_D7_RX)
/I2C_SCL: J2.5, R2.2, U1.6 (GPIO6_A5_D5_SCL), U2.4
/I2C_SDA: J2.6, R1.2, U1.5 (GPIO5_A4_D4_SDA), U2.3
/NC: J3.5, J3.6
/NODE_RX_FROM_TEENSY: J3.4, U1.1 (GPIO1_A0_D0)
/NODE_TX_TO_TEENSY: J3.3, U1.2 (GPIO2_A1_D1)
GND: C1.2, J2.3, J3.1, U1.13 (GND), U2.1

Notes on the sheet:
I2C pull-ups to 3.3 V only
GPS module powered from 5 V
+3V3 generated by XIAO regulator
Pins 5 and 6 reserved / no-connect.
Do not power from USB and Teensy 5 V at the same time unless power isolation is added.
5 V supplied from Teensy cable.
Design intent: XIAO ESP32-S3 based airspeed node. All external sensor logic is 3.3 V. Airspeed sensor connects by I2C. No 5 V pull-ups on SDA/SCL.

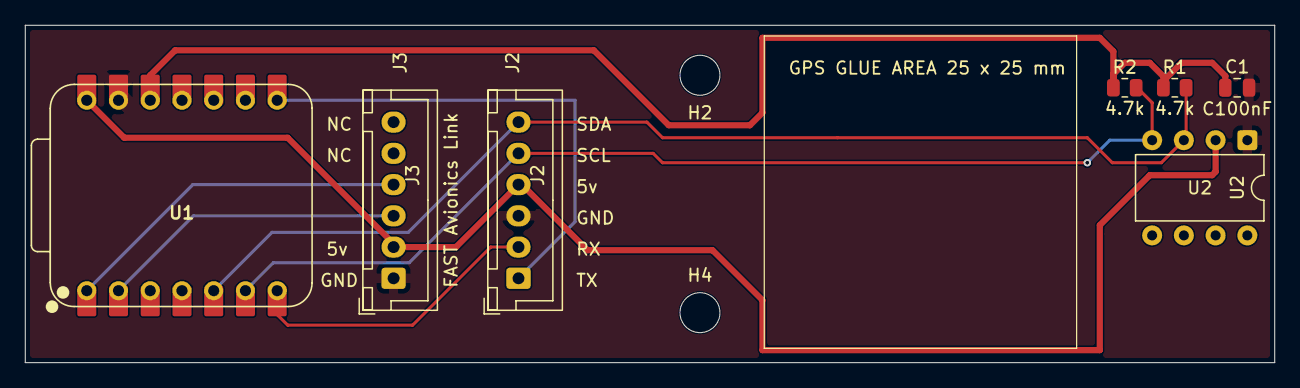
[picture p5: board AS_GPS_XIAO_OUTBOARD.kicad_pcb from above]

Board: 2 copper layers, 100.0 x 27.0 mm, 9 parts (0 on the bottom side), 10 nets.

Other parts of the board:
H2, H4: 3.2mm_M3; MountingHole_3.2mm_M3

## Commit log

2026-07-03 Add FAST avionics KiCad projects
    [AS_GPS_XIAO_OUTBOARD-B_Cu.gbr, AS_GPS_XIAO_OUTBOARD-B_Mask.gbr, AS_GPS_XIAO_OUTBOARD-B_Paste.gbr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]
2026-09-04 Add FAST Controller V2 design and manufacturing files
    [FAST Controller-B_Cu.gbl, FAST Controller-B_Mask.gbs, FAST Controller-B_Silkscreen.gbo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]
2026-09-10 Release FAST Controller V2.1 production corrections
    [FAST Controller-B_Cu.gbl, FAST Controller-B_Mask.gbs, FAST Controller-B_Silkscreen.gbo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]
2026-09-17 Release FAST Controller V2.2 servo power correction
    [FAST Controller-B_Cu.gbl, FAST Controller-B_Mask.gbs, FAST Controller-B_Silkscreen.gbo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]
2026-09-18 Update FAST Controller V2.2 schematic and ground stitching
    [FAST Controller.kicad_pcb, FAST Controller.kicad_sch]
